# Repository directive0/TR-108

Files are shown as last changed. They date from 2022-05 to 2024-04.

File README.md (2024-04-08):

#
This repository hosts a set of design documents for the TR-108 Picorder. A Picorder is a Raspberry Pi based handheld device that records and displays sensor data for immediate analysis. The TR-108 is designed to use a Raspberry Pi Zero W, a set of custom designed PCBs, and a 3D printed enclosure to achieve this goal. This project, along with [PicorderOS](https://squaredwave.com/wiki/index.php?title=PicorderOS) attempts to be a single self contained solution for anyone wishing to build their own Picorder.

## What is included:

- The design_docs folder contains a crude SVG file that shows the 2D layout of the original design, mostly to scale. The SVG includes a crude wiring diagram.

- The pcb_design folder contains KiCad files of the proposed printed circuit board to replace the original perfboard prototype. These files can be used to produce and test PCBs.

- The enclosure_design folder contains STLs (incomplete) and a .blend file containing the raw construction file for a complete enclosure, based closely on the DST Tricorder toy.

## What is not yet included:

- There are no assembly instructions. I hope to produce some in the future.

While it is not required, if you make a picorder using this repository I would appreciate you sharing photos or videos your build with me at chris@squaredwave.com.

For a more regularly updated description of this project please visit the [wiki](https://squaredwave.com/wiki/index.php?title=Picorder)

Originally designed by Chris Barrett in 2017. I consider this project to be "Open Hardware", and as such is free to use, modify distribute or sell. It comes with no promise of support or warranty.

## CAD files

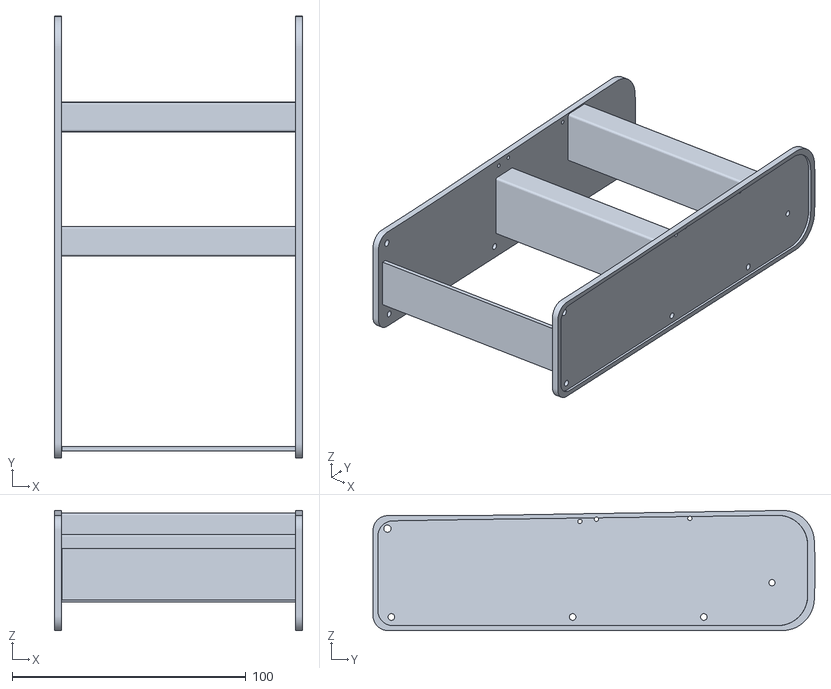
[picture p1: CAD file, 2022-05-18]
enclosure_design/STLs/Main Body Frame.stl
106.3 x 189.2 x 51.4

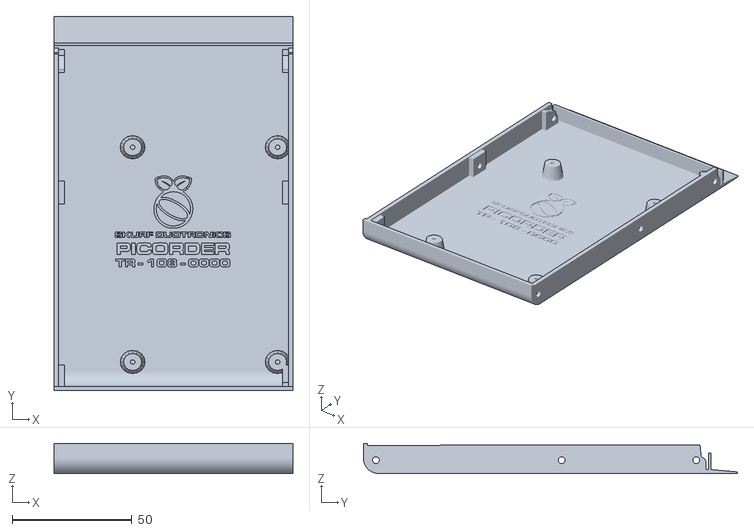
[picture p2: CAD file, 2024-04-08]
enclosure_design/STLs/Back Plane.stl
99.8 x 156.3 x 12.5

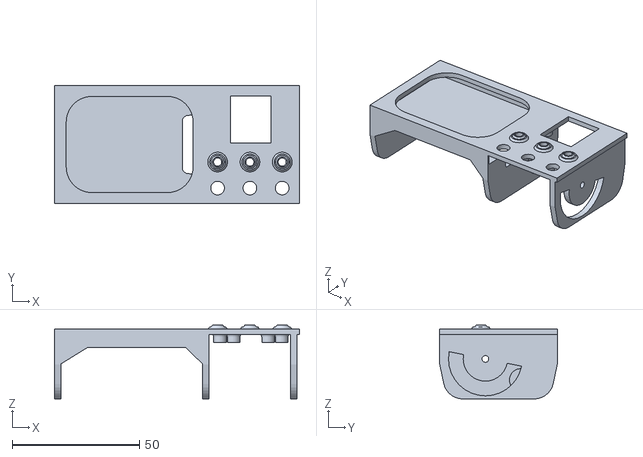
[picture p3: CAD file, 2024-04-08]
enclosure_design/STLs/DISMO Front Plate.stl
96.3 x 46.2 x 29.0

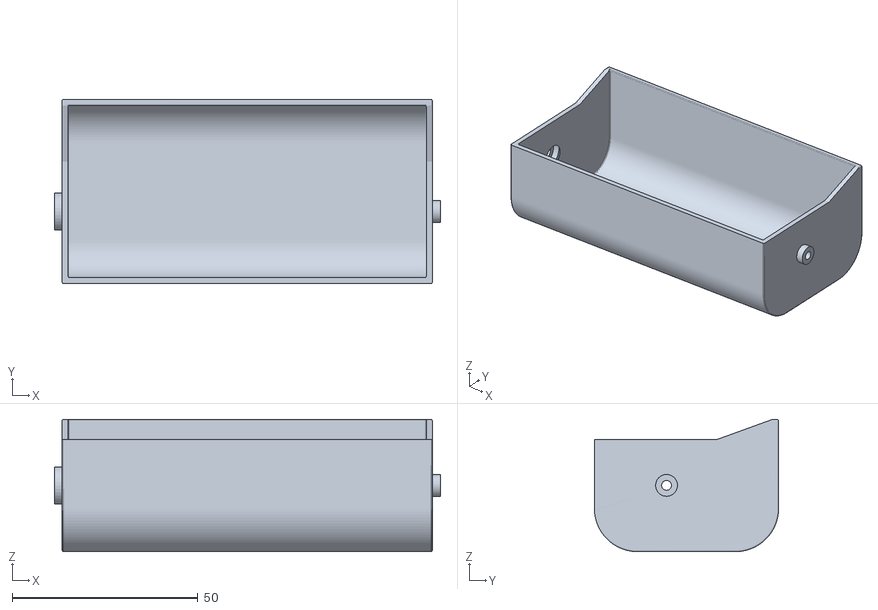
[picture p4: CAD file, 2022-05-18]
enclosure_design/STLs/DISMO Shroud.stl
103.9 x 49.6 x 35.6

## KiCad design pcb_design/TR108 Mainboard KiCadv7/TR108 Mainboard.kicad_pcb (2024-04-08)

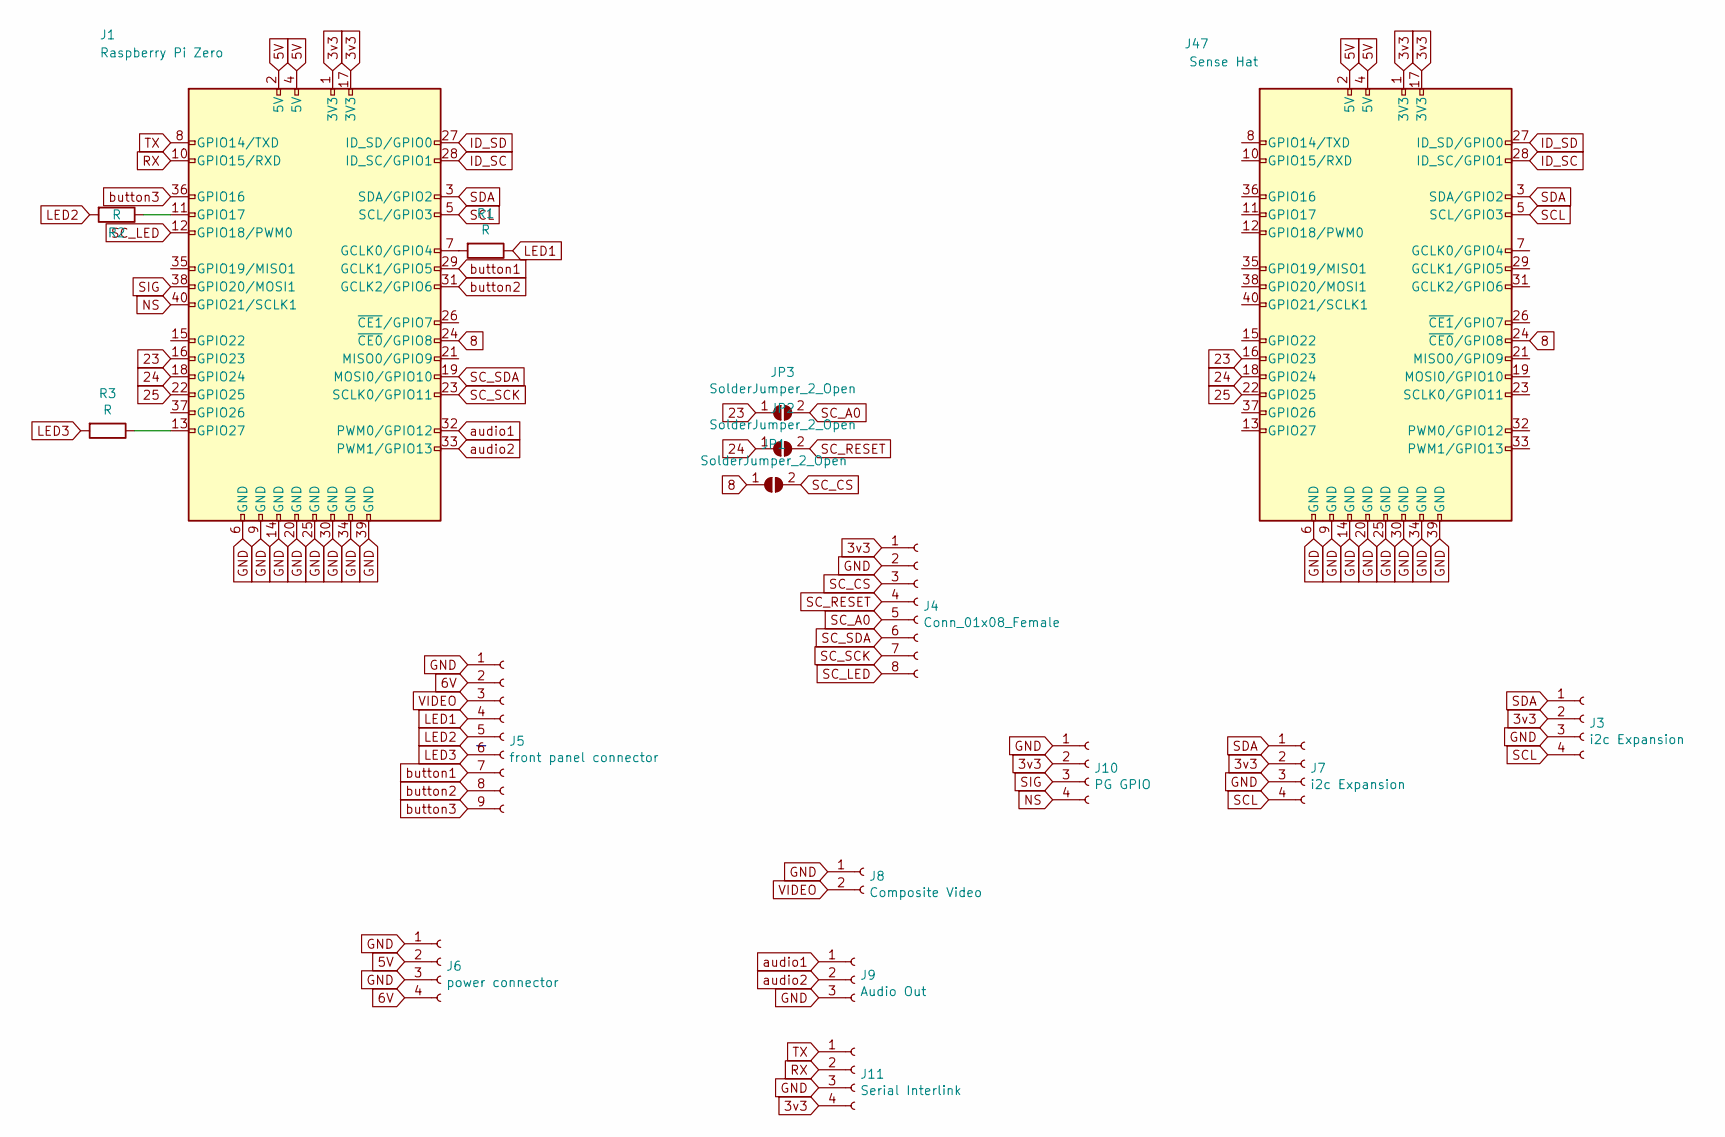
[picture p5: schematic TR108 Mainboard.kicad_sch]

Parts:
J1: Raspberry Pi Zero; PinHeader_2x20_P2.54mm_Vertical
J3, J7: i2c Expansion; PinHeader_1x04_P2.54mm_Vertical
J4: Conn_01x08_Female; PinHeader_1x08_P2.54mm_Vertical
J5: front panel connector; PinHeader_1x09_P2.54mm_Vertical
J6: power connector; PinHeader_1x04_P2.54mm_Vertical
J8: Composite Video; PinHeader_1x02_P2.54mm_Vertical
J9: Audio Out; PinHeader_1x03_P2.54mm_Vertical
J10: PG GPIO; PinHeader_1x04_P2.54mm_Vertical
J11: Serial Interlink; PinHeader_1x04_P2.54mm_Vertical
J47: Sense Hat; PinHeader_2x20_P2.54mm_Vertical
JP1, JP2, JP3: SolderJumper_2_Open; SolderJumper-2_P1.3mm_Open_RoundedPad1.0x1.5mm
R1, R2, R3: R; R_0805_2012Metric_Pad1.20x1.40mm_HandSolder

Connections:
3v3: J1.1 (3V3), J1.17 (3V3), J3.2, J4.1, J7.2, J10.2, J11.4, J47.1 (3V3), J47.17 (3V3); also elsewhere on the board
5V: J1.2 (5V), J1.4 (5V), J6.2, J47.2 (5V), J47.4 (5V); also elsewhere on the board
6V: J5.2, J6.4
8: J1.24 (~CE0/GPIO8), J47.24 (~CE0/GPIO8), JP1.1 (A); also elsewhere on the board
23: J1.16 (GPIO23), J47.16 (GPIO23), JP3.1 (A); also elsewhere on the board
24: J1.18 (GPIO24), J47.18 (GPIO24), JP2.1 (A); also elsewhere on the board
25: J1.22 (GPIO25), J47.22 (GPIO25); also elsewhere on the board
GND: J1.6 (GND), J1.9 (GND), J1.14 (GND), J1.20 (GND), J1.25 (GND), J1.30 (GND), J1.34 (GND), J1.39 (GND), J3.3, J4.2, J5.1, J6.1, J6.3, J7.3, J8.1, J9.3, J10.1, J11.3, J47.6 (GND), J47.9 (GND), J47.14 (GND), J47.20 (GND), J47.25 (GND), J47.30 (GND), J47.34 (GND), J47.39 (GND); also elsewhere on the board
ID_SC: J1.28 (ID_SC/GPIO1), J47.28 (ID_SC/GPIO1); also elsewhere on the board
ID_SD: J1.27 (ID_SD/GPIO0), J47.27 (ID_SD/GPIO0); also elsewhere on the board
LED1: J5.4, R1.1
LED2: J5.5, R2.2
LED3: J5.6, R3.2
NS: J1.40 (GPIO21/SCLK1), J10.4
unnamed: J1.7 (GCLK0/GPIO4), R1.2
unnamed: J1.11 (GPIO17), R2.1
unnamed: J1.13 (GPIO27), R3.1
RX: J1.10 (GPIO15/RXD), J11.2
SCL: J1.5 (SCL/GPIO3), J3.4, J7.4, J47.5 (SCL/GPIO3); also elsewhere on the board
SC_A0: J4.5, JP3.2 (B)
SC_CS: J4.3, JP1.2 (B)
SC_LED: J1.12 (GPIO18/PWM0), J4.8
SC_RESET: J4.4, JP2.2 (B)
SC_SCK: J1.23 (SCLK0/GPIO11), J4.7
SC_SDA: J1.19 (MOSI0/GPIO10), J4.6
SDA: J1.3 (SDA/GPIO2), J3.1, J7.1, J47.3 (SDA/GPIO2); also elsewhere on the board
SIG: J1.38 (GPIO20/MOSI1), J10.3
TX: J1.8 (GPIO14/TXD), J11.1
VIDEO: J5.3, J8.2
audio1: J1.32 (PWM0/GPIO12), J9.1
audio2: J1.33 (PWM1/GPIO13), J9.2
button1: J1.29 (GCLK1/GPIO5), J5.7
button2: J1.31 (GCLK2/GPIO6), J5.8
button3: J1.36 (GPIO16), J5.9

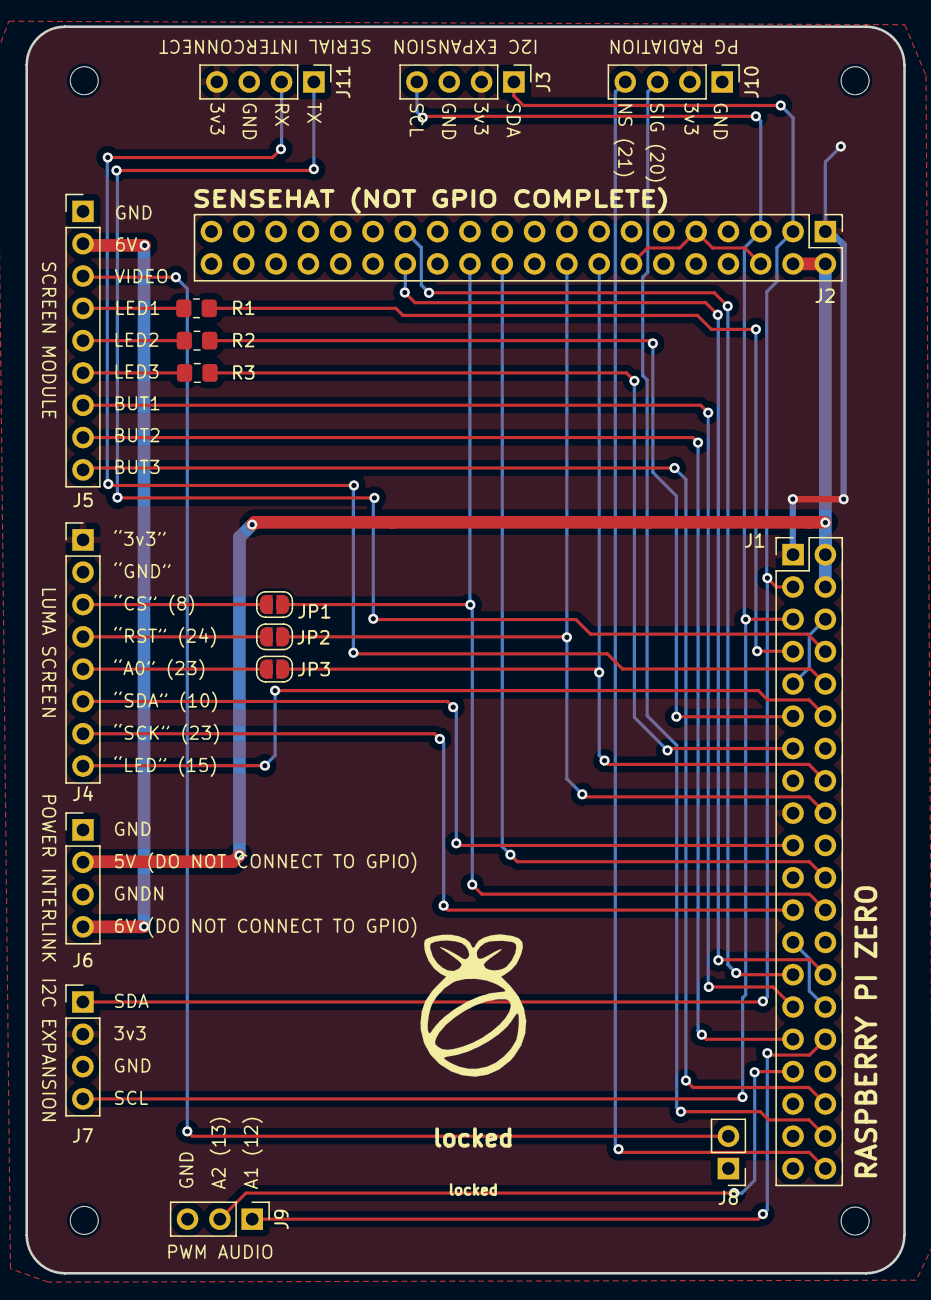
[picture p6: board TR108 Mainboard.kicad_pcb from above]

Board: 2 copper layers, 69.0 x 98.0 mm, 17 parts (0 on the bottom side), 34 nets.

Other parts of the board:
J2: Sense Hat; PinHeader_2x20_P2.54mm_Vertical

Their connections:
3v3: J2.1 (3V3), J2.17 (3V3); also elsewhere on the board
5V: J2.2 (5V), J2.4 (5V); also elsewhere on the board
8: J2.24 (~CE0/GPIO8); also elsewhere on the board
23: J2.16 (GPIO23); also elsewhere on the board
24: J2.18 (GPIO24); also elsewhere on the board
25: J2.22 (GPIO25); also elsewhere on the board
GND: J2.6 (GND), J2.9 (GND), J2.14 (GND), J2.20 (GND), J2.25 (GND), J2.30 (GND), J2.34 (GND), J2.39 (GND); also elsewhere on the board
ID_SC: J2.28 (ID_SC/GPIO1); also elsewhere on the board
ID_SD: J2.27 (ID_SD/GPIO0); also elsewhere on the board
SCL: J2.5 (SCL/GPIO3); also elsewhere on the board
SDA: J2.3 (SDA/GPIO2); also elsewhere on the board

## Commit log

2021-06-16 File populate
    [TR108 Mainboard.kicad_pcb, TR108 Mainboard.sch]
2021-06-29 Update to PCB
    [TR108 Mainboard.kicad_pcb, TR108 Mainboard.sch]
2022-05-18 mass update - new blend and pcb
    [Main Body Frame.stl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]
2022-05-18 STL changes
    [Back Plane.stl, DISMO Front Plate.stl, DISMO Shroud.stl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]
2024-04-08 cleanup, Blend update, new PCB
    [Back Plane.stl, DISMO Front Plate.stl, TR108 Mainboard.kicad_pcb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]
